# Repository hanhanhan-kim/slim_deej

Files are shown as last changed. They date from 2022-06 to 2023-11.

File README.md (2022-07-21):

# Slim Deej

*A small form factor Deej that frees up desk space.*

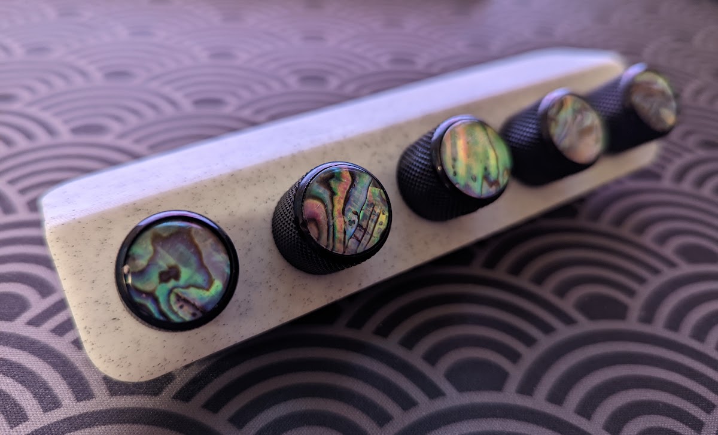
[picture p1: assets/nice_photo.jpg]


This project provides hardware for the awesome [Deej](https://github.com/omriharel/deej) volume mixer (Windows and Linux only). The Deej community has come up with many myriad designs, but I didn't find one that suited my needs. So I made one! This Deej design is fairly low profile, and can be mounted under one's desk or monitor, so it doesn't take up any valuable desk space. For this reason, I'm using rotary potentiometers, because sliding potentiometers take up a lot of real estate. I also designed a PCB, to ease the assembly process, and slim down the form factor. A slight upward angle on the front panel adds to the aesthetic. The original [`.f3d` ](./3d_files/case_front.f3d) file is parameterized, however, and so the angle can be easily adjusted. For example, a 90 degree version is available [here](). 

## BOM

In addition to standard electronics equipment and access to a 3D-printer:

| Item | Price (USD) | Quantity | Source |
| --- | --- | --- | --- |
| Arduino Pro Micro* | 27.99 / 3 | 1 | Amazon<br />[ASIN B01MTU9GOB](https://www.amazon.com/HiLetgo-Atmega32U4-Bootloadered-Development-Microcontroller/dp/B01MTU9GOB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) |
| PCB | 5.40 / 5 | 1 | [JLCPCB](https://jlcpcb.com/) |
| Rotary potentiometer (10 kΩ ) | 2.23 | 5 | [Digikey 987-1666-ND](https://www.digikey.com/en/products/detail/tt-electronics-bi/P0915N-EC15BR10K/4780755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) |
| *Optional*: Knobs | 0 - lots | 5 | Can be printed (e.g. [here](https://www.thingiverse.com/thing:54024) or [here](https://www.thingiverse.com/thing:1072393)), or bought. Just make sure it's for 6 mm diameter shafts. Guitar knobs are often of the correct size. |

**Note*: I used an Arduino Pro Micro clone, to cut down on price. Any microcontroller with the ATmega 32U4 processor and a Pro Micro footprint and pinout should be fine, e.g. the [Sparkfun Pro Micro](https://www.sparkfun.com/products/12640). Unfortunately, the supply chain shortage has affected things, and microcontrollers are more expensive than they used to be.

## Circuit

Here's a schematic of the circuit. It's very simple, just a GND rail and a VCC rail, and each potentiometer gets its own analog pin:

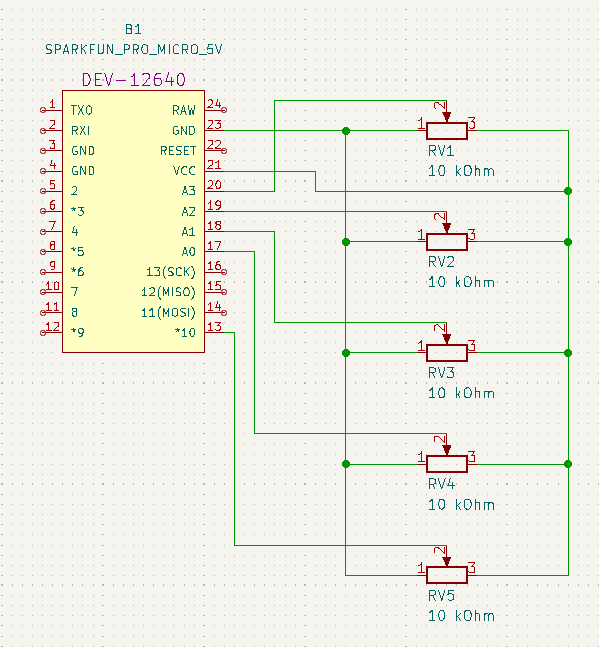
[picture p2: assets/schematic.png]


Here's the circuit PCB, with a view from the back side: 

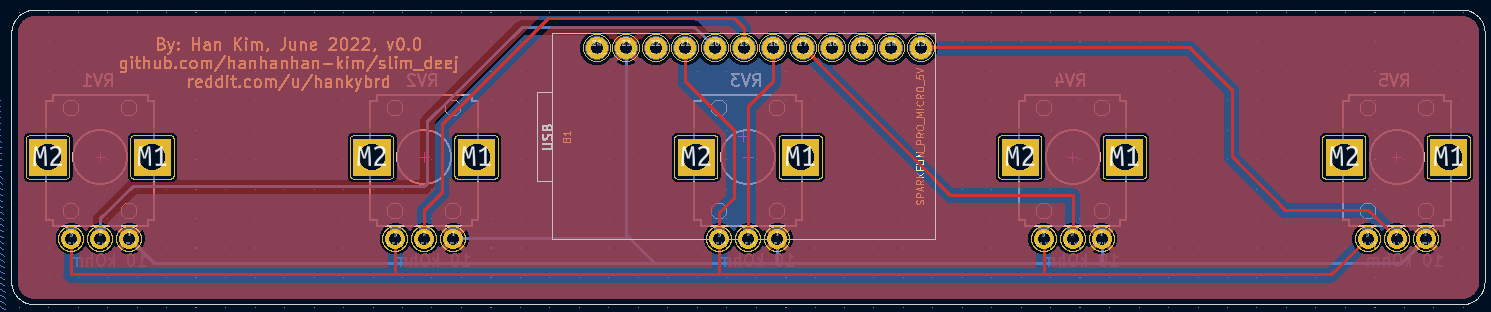
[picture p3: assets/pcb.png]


The KiCad source files are available [here](./kicad_slim_deej/). 

## Installation

Installation is fairly straightforward. Print the [panel case](./3d_files/case_front.3mf), a render of which is shown: 

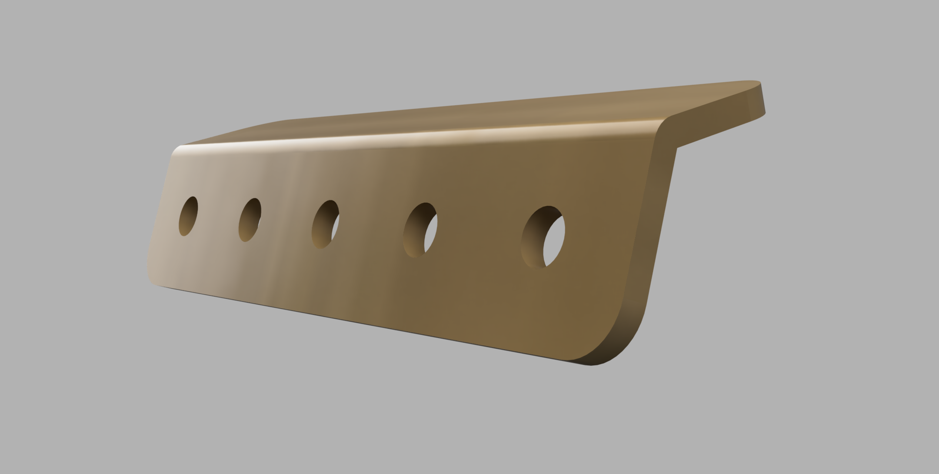
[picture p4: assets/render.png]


Solder the rotary potentiometers *first*. Then solder the microcontroller onto the other side of the PCB (only one side of the microcontroller pins will be soldered onto the PCB). Make sure the USB port is facing the text, like so:

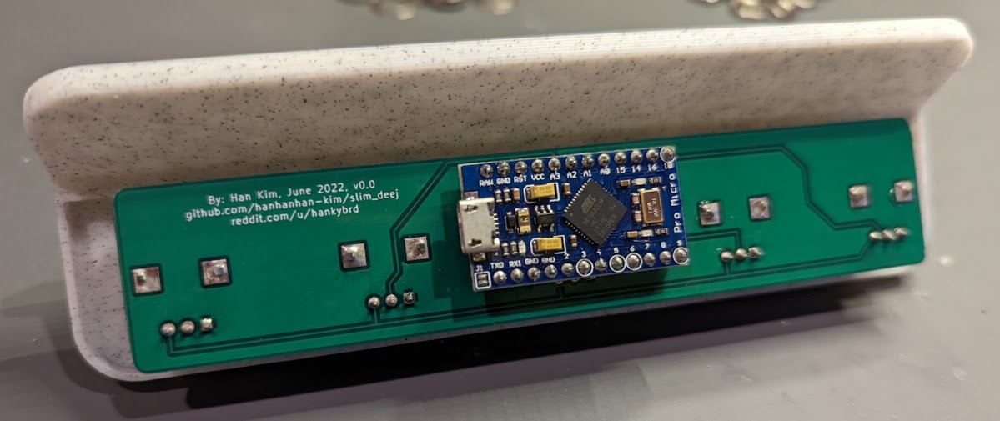
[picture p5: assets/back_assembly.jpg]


Then, using the washers and nuts that come with the potentiometers to affix the PCB to the case:

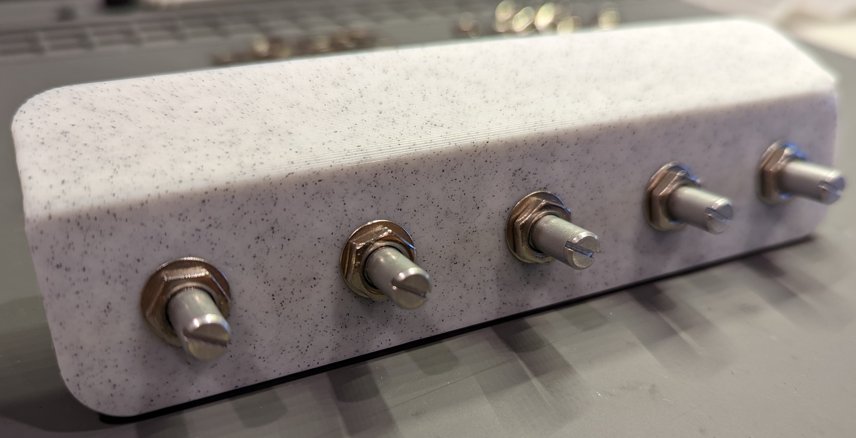
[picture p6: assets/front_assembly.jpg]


Then, upload the [firmware provided](./arduino_deej_5_knobs/arduino_deej_5_knobs.ino), using the Arduino IDE. This firmware differs from the [one in the official Deej Github repo](https://github.com/omriharel/deej/tree/master/arduino/deej-5-sliders-vanilla), only in that the specified pins correspond to the potentiometers, from left to right on the panel. Finally, download the [Deej software and configuration file](https://github.com/omriharel/deej/releases/tag/v0.9.10) from the official Deej repo, and make sure the Deej configuration file specifies the correct port. Then, edit the configuration file to your heart's desire, and enjoy your Deej! Read the [official Deej docs](https://github.com/omriharel/deej#software) for more details! The Slim Deej can be mounted with a command strip (my preferred method), or hot glue, or whatever tickles your fancy. 

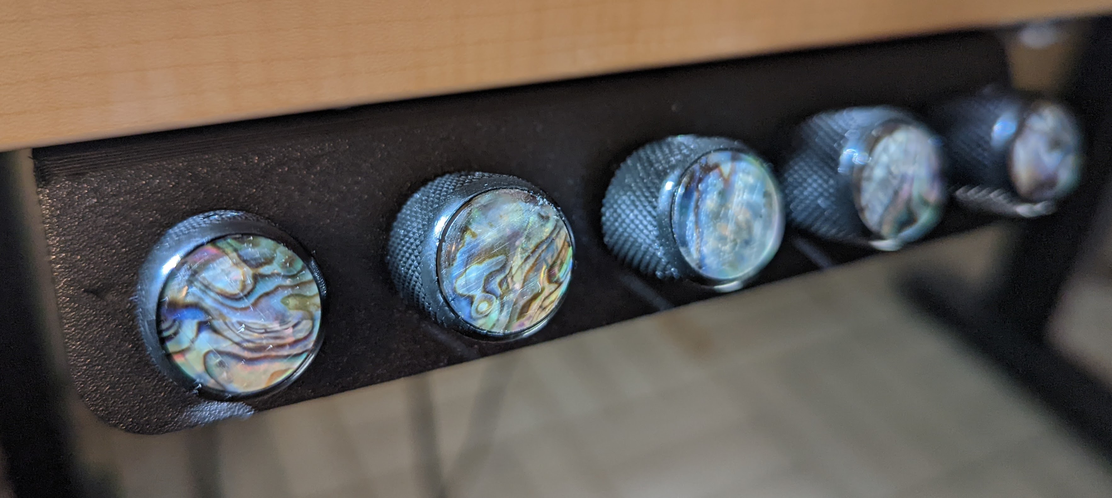
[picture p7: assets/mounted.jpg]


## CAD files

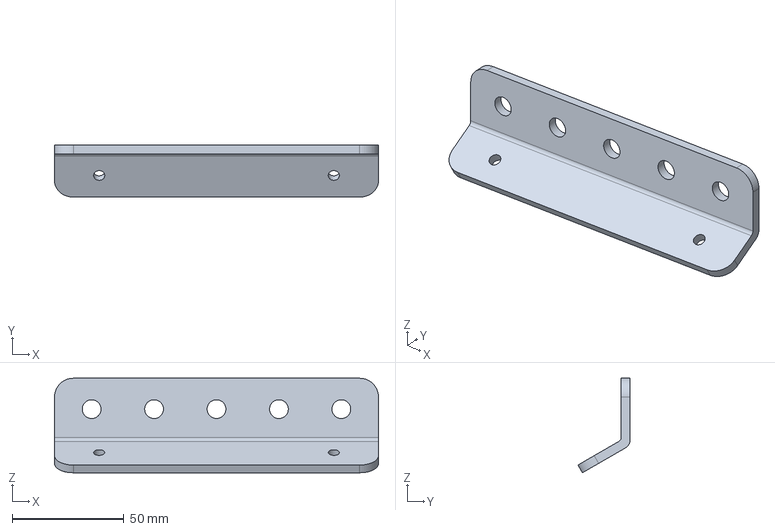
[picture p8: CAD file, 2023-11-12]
3d_files/case_front_4-sheet-metal.step
145.0 x 23.3 x 42.3 mm

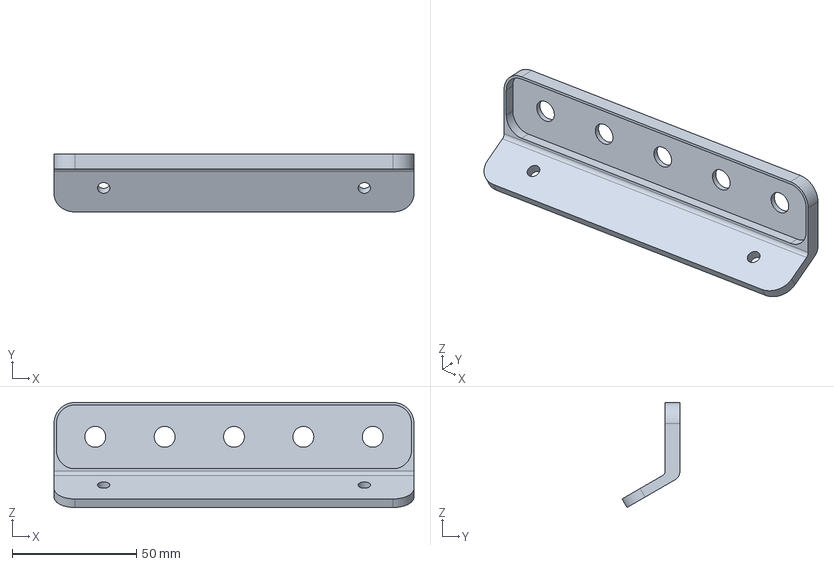
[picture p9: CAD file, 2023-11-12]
3d_files/case_front.step
145.0 x 23.3 x 42.3 mm

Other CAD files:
3d_files/case_front.3mf
3d_files/case_front.f3d

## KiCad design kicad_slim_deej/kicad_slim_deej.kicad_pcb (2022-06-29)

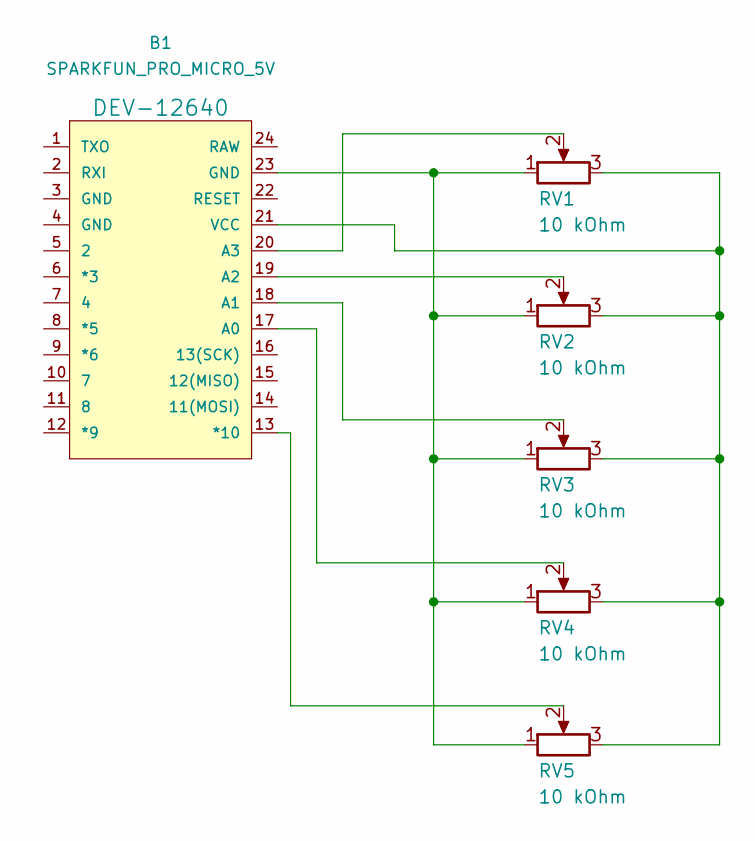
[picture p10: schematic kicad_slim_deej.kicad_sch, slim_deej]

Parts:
B1: SPARKFUN_PRO_MICRO_5V; SPARKFUN_PRO_MICRO_ANALOG_HALF
RV1, RV2, RV3, RV4, RV5: 10 kOhm; R0904N

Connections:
unnamed: B1.13 (*10), RV5.2
unnamed: B1.17 (A0), RV4.2
unnamed: B1.18 (A1), RV3.2
unnamed: B1.19 (A2), RV2.2
unnamed: B1.20 (A3), RV1.2
unnamed: B1.21 (VCC), RV1.3, RV2.3, RV3.3, RV4.3, RV5.3
unnamed: B1.23 (GND), RV1.1, RV2.1, RV3.1, RV4.1, RV5.1

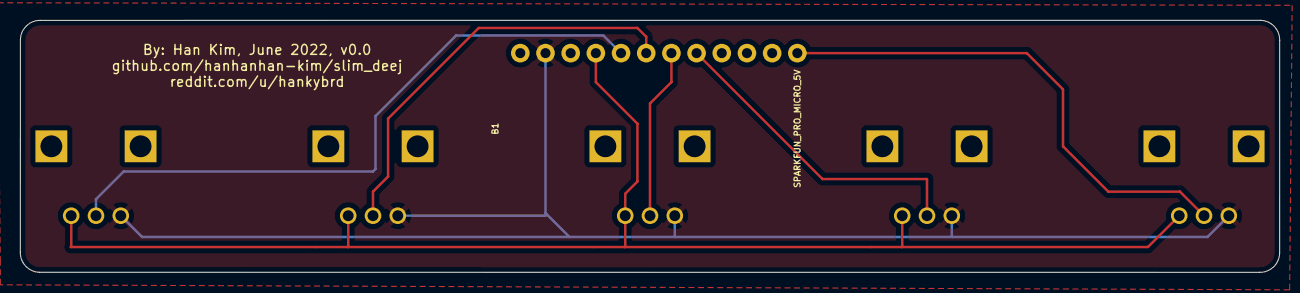
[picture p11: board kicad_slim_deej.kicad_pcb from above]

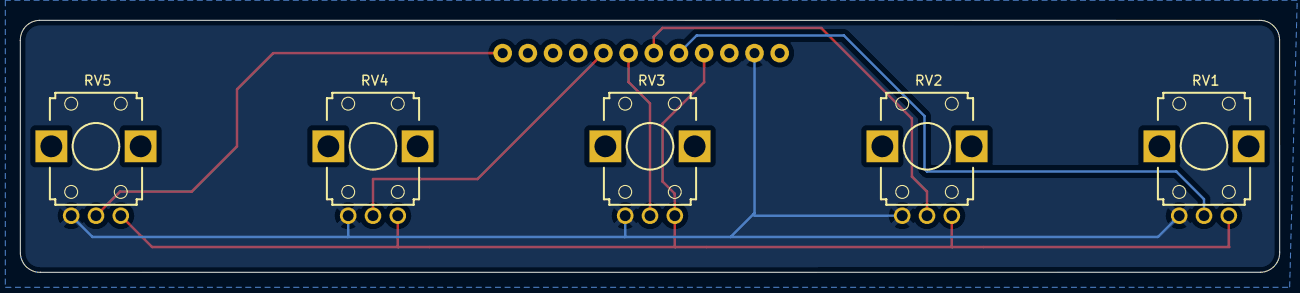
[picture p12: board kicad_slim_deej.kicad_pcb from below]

Board: 2 copper layers, 127.0 x 25.4 mm, 6 parts (5 on the bottom side), 7 nets.

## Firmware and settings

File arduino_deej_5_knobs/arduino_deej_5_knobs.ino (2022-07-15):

const int NUM_SLIDERS = 5;
const int analogInputs[NUM_SLIDERS] = {A10, A0, A1, A2, A3};

int analogSliderValues[NUM_SLIDERS];

void setup() { 
  for (int i = 0; i < NUM_SLIDERS; i++) {
    pinMode(analogInputs[i], INPUT);
  }

  Serial.begin(9600);
}

void loop() {
  updateSliderValues();
  sendSliderValues(); // Actually send data (all the time)
  // printSliderValues(); // For debug
  delay(10);
}

void updateSliderValues() {
  for (int i = 0; i < NUM_SLIDERS; i++) {
     analogSliderValues[i] = analogRead(analogInputs[i]);
  }
}

void sendSliderValues() {
  String builtString = String("");

  for (int i = 0; i < NUM_SLIDERS; i++) {
    builtString += String((int)analogSliderValues[i]);

    if (i < NUM_SLIDERS - 1) {
      builtString += String("|");
    }
  }
  
  Serial.println(builtString);
}

void printSliderValues() {
  for (int i = 0; i < NUM_SLIDERS; i++) {
    String printedString = String("Slider #") + String(i + 1) + String(": ") + String(analogSliderValues[i]) + String(" mV");
    Serial.write(printedString.c_str());

    if (i < NUM_SLIDERS - 1) {
      Serial.write(" | ");
    } else {
      Serial.write("\n");
    }
  }
}

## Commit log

2022-06-29 init
    - add PCB design
    - add case design
    - first time doing multiline commits! hehe
    [case_front.3mf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]
2022-07-03 recentre hole positions
    [case_front.3mf]
2022-07-15 adjust case and add firmware: - make case panel front thinner, so that the threads of the pots can extend past the case - add firmware with correct knob order from left to right
    [case_front.3mf]
2022-07-15 rename some files and add docs
    [kicad_slim_deej.kicad_pcb, kicad_slim_deej.kicad_sch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]
2022-07-15 add mounted img
2022-07-17 add more 3dp files and change license: - change license on kicad schematic to CC (NC-SA) - add .f3z and .step files of case front panel - update readme to reflect these changes
    [case_front.3mf, case_front.f3d, case_front.step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]
2022-07-21 add 90 deg alt
    [case_front_alt_90_deg.3mf]
2023-11-12 add mounting holes + file for sheet metal
    [case_front.3mf, case_front.f3d, case_front.step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]

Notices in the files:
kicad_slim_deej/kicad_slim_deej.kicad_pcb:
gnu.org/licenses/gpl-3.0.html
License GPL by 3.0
